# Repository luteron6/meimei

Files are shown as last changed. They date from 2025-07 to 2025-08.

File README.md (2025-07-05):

# meimei
A simple, wireless, 75% keyboard! Not too big or small. It runs ZMK.



# Why?
My first exposure to keyboards was through Hack Club's #hackpad, in which I made a 5-key macropad with an encoder and screen. I've never had a regular mechanical keyboard, and this is my attempt at making one. It has a function row, all the necessary keys for typing, and a rotary encoder. Since I mainly use a laptop, I wanted this keyboard to be fully wireless.

## Code - ZMK
After watching many [Joe Scotto](https://www.youtube.com/@joe_scotto) videos, I came to the conclusion that the only reasonable microcontroller to use was the [nice!nano v2](https://nicekeyboards.com/docs/nice-nano/pinout-schematic).

It's suggested to run ZMK as the firmware for bluetooth, so I learned ZMK for this keyboard. Previously I've used QMK, but ZMK is quite different as it uses a Github Actions workflow to compile the firmware file. The firmware for this keyboard lives in [this](https://github.com/luteron6/zmk-config-meimei) repository. Simply go to the [Actions](https://github.com/luteron6/zmk-config-meimei/actions) tab, open the most recent workflow, download the firmware Artifact, unzip the firmware, and flash it to the nice!nano. 

All the source files for ZMK are in the /Code folder in this repository.

## PCB
I made the PCB in KiCad, using [Joe Scotto's symbol/footprint/3D model library](https://github.com/joe-scotto/scottokeebs/tree/main/Extras/ScottoKicad).

It was really helpful as his footprints had 3D models linked to them, because it transferred into Onshape when I worked on my CAD. I included a power button to turn off the keyboard when I travel with it, and an encoder for good measure.

I chose to go with the biggest reasonable battery for this project, so I chose a 3048128 3400mAh battery. According to the [ZMK Power Profiler](https://zmk.dev/power-profiler), this keyboard will last 1 year and 1 month. So basically forever. And ZMK can report battery usage over bluetooth, so this keyboard will literally never die.

The PCB files are in the /PCB folder, including the KiCad source files and the Gerbers for production.



## CAD
As mentioned above, the CAD was made in Onshape. The case has two parts, both of which are in the /CAD folder along with the STEP file of everything. It's meant to be 3D printed and screwed together using threaded inserts and M2 screws.

## BOM
| Item | QTY Needed | QTY Purchased | Price | Description | Link |
|---|---|----|---|---|---|
| Keyswitches | 74 | 90 | $27.98  | Clicky switches | [Link](https://www.amazon.com/Akko-Keyboard-Diffuser-Mechanical-Structure/dp/B0DJNSK6TD/) |
| Keycaps (Japanese Maple) | | | $25.99  | | [Link](https://www.amazon.com/Japanese-Keycaps-Sublimation-Mechanical-Keyboard/dp/B08Y6S1N3X/) |
| nice!nano | 1 | 1  | $24.99  | microcontroller | [Link](https://www.littlekeyboards.com/products/nice-nano) |
| PCB | 1 | 5  | $30.00  | JLCPCB (also includes shipping) | |
| diodes | 70 | 125 | $5.99  | SOD-123 package diodes | [Link](https://www.amazon.com/100-Pieces-1N4148W-Switching-High-Speed/dp/B079KJX5J9/) |
| Stabilizers | | | $18.99  | Spacebar/2u stabilizers | [Link](https://www.amazon.com/DUROCK-Stabilizers-Translucent-Keyboard-Mechanical/dp/B0B2RVN19F/) |
| peel-away sockets | 2 | 2  | $6.00 | socketing the microcontroller | [Link](https://ringerkeys.com/products/peel-a-way-sockets?variant=40212560576594) |
| peel-away pins | 2 | 2  | $6.00 | socketing the microcontroller | [Link](https://ringerkeys.com/products/peel-a-way-sockets?variant=40212560609362) |
| Battery | 1 | 1  | $8.99 | A 3048128 3400mAh battery | [Link](https://www.amazon.com/YTKavq-3400mAh-Battery-Rechargeable-Connector/dp/B08TTJ79JV/) |
| Latching Switches | 1 | 3  | $7.99 | Power on/off switch | [Link](https://www.amazon.com/Gebildet-Prewired-Waterproof-Self-Locking-Stainless/dp/B0BXPFW69R/) |
| littlekeyboards shipping | | | $6.00 | | |
| ringerkeys shipping | | | $6.00 | | |
| Total | | | $174.92 | | |

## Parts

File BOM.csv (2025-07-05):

Item | QTY Needed | QTY Purchased | Price | Description | Link
Keyswitches | 74 | 90 | $27.98 | Clicky switches | https://www.amazon.com/Akko-Keyboard-Diffuser-Mechanical-Structure/dp/B0DJNSK6TD/
Keycaps (Japanese Maple) |  |  | $25.99 |  | https://www.amazon.com/Japanese-Keycaps-Sublimation-Mechanical-Keyboard/dp/B08Y6S1N3X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
nice!nano | 1 | 1 | $24.99 | microcontroller | https://www.littlekeyboards.com/products/nice-nano
PCB | 1 | 5 | $30.00 | JLCPCB (also includes shipping)
diodes | 70 | 125 | $5.99 | SOD-123 package diodes | https://www.amazon.com/100-Pieces-1N4148W-Switching-High-Speed/dp/B079KJX5J9/
Stabilizers |  |  | $18.99 | Spacebar/2u stabilizers | https://www.amazon.com/DUROCK-Stabilizers-Translucent-Keyboard-Mechanical/dp/B0B2RVN19F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
peel-away sockets | 2 | 2 | $6.00 | socketing the microcontroller | https://ringerkeys.com/products/peel-a-way-sockets?variant=40212560576594
peel-away pins | 2 | 2 | $6.00 | socketing the microcontroller | https://ringerkeys.com/products/peel-a-way-sockets?variant=40212560609362
Battery | 1 | 1 | $8.99 | A 3048128 3400mAh battery | https://www.amazon.com/YTKavq-3400mAh-Battery-Rechargeable-Connector/dp/B08TTJ79JV/
Latching Switches | 1 | 3 | $7.99 | Power on/off switch | https://www.amazon.com/Gebildet-Prewired-Waterproof-Self-Locking-Stainless/dp/B0BXPFW69R/
littlekeyboards shipping |  |  | $6.00
ringerkeys shipping |  |  | $6.00
Total |  |  | $174.92

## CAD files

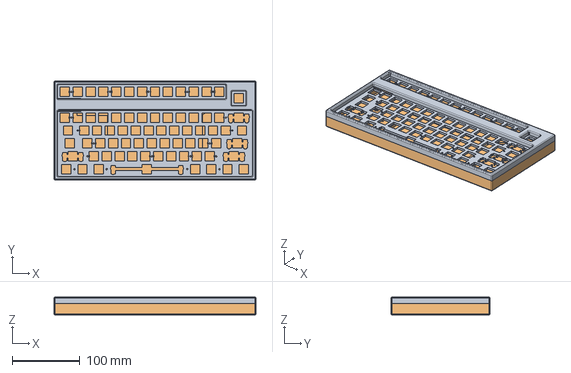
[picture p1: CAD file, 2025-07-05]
CAD/Assembly.step
298.5 x 146.1 x 26.6 mm

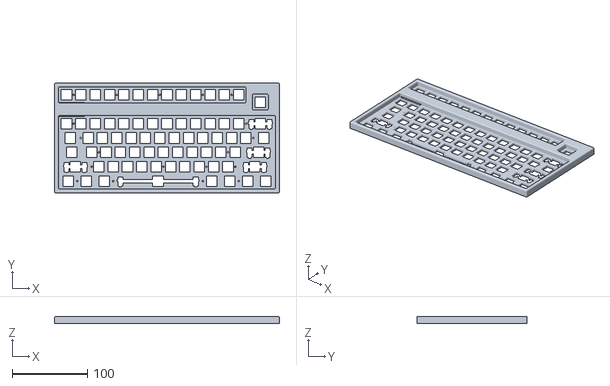
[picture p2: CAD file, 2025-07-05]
CAD/top.stl
298.5 x 146.1 x 9.60

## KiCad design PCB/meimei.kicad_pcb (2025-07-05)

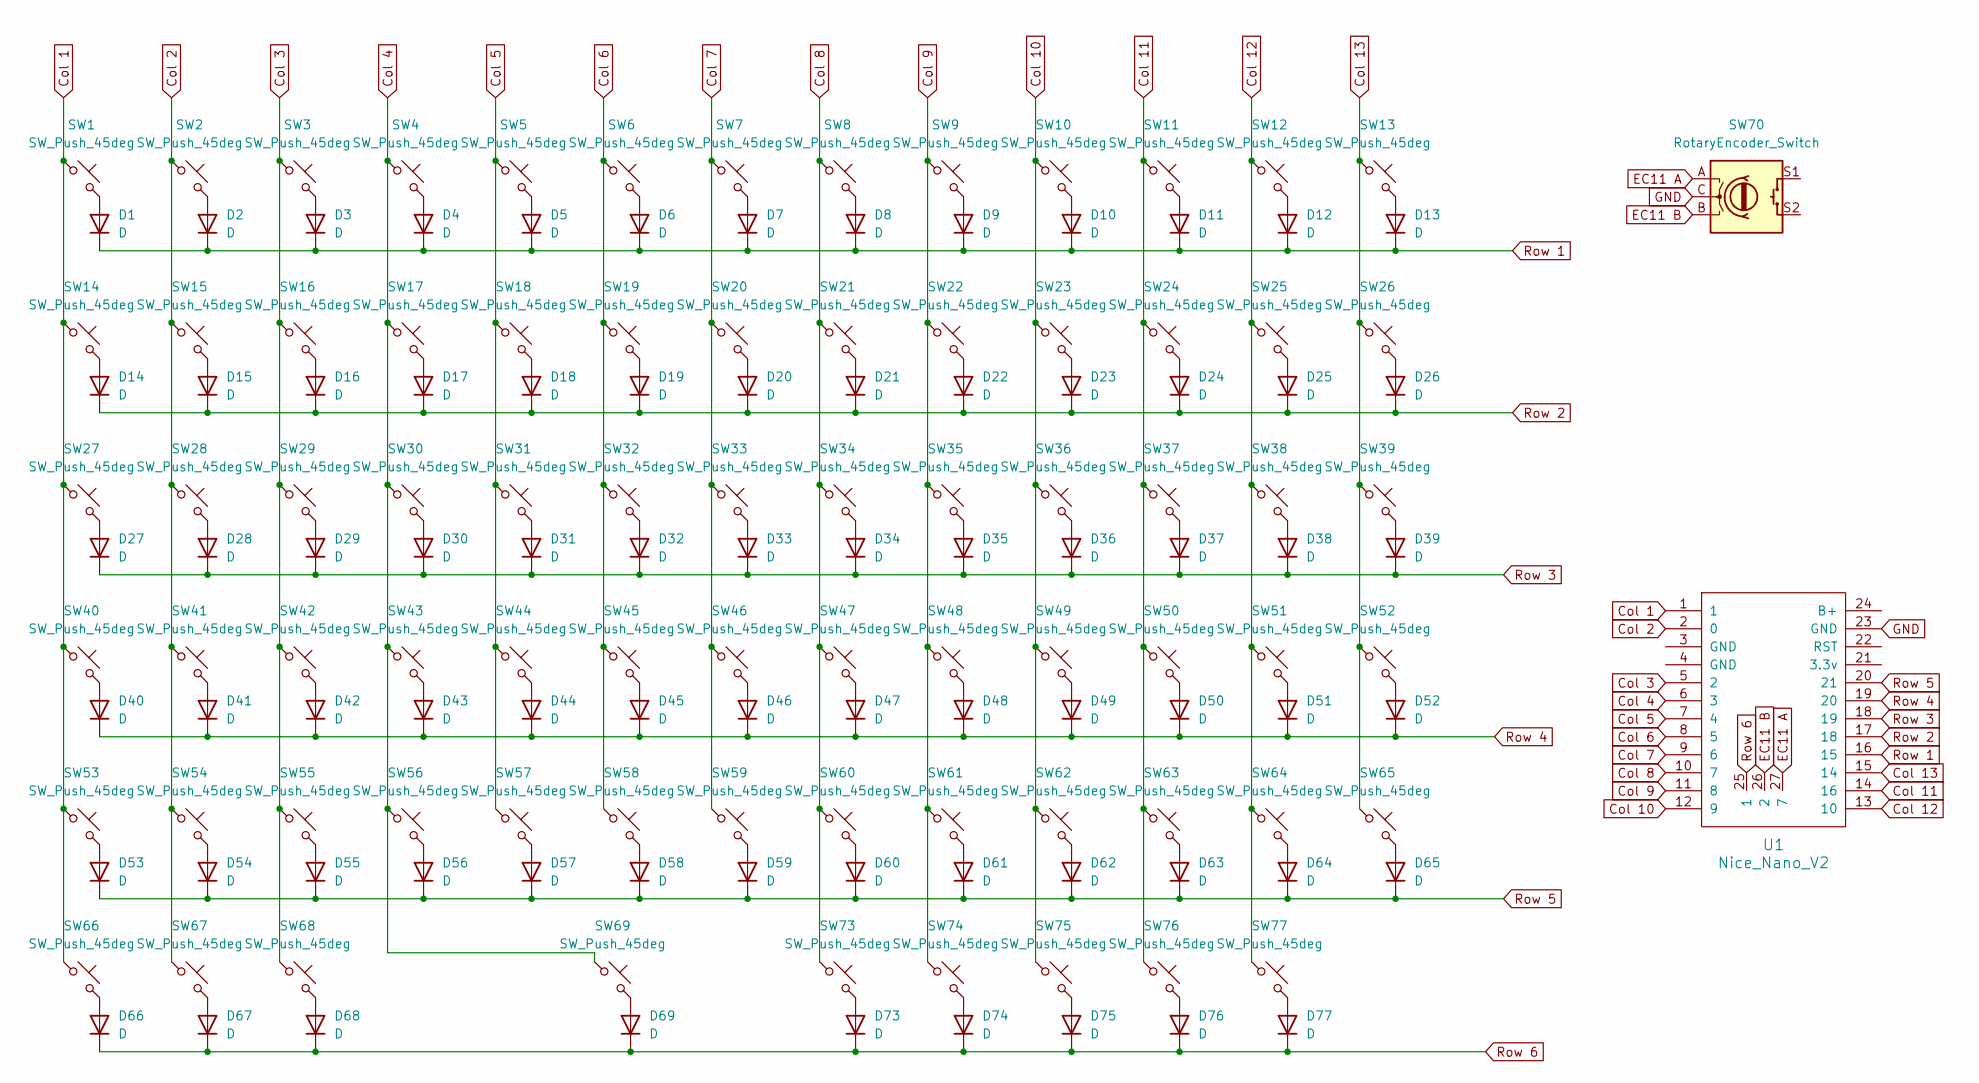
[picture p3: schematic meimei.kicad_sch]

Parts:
D1, D2, D3, D4, D5, D6, D7, D8, D9, D10, D11, D12, D13, D14, D15, D16, D17, D18, D19, D20, D21, D22, D23, D24, D25, D26, D27, D28, D29, D30, D31, D32, D33, D34, D35, D36, D37, D38, D39, D40, D41, D42, D43, D44, D45, D46, D47, D48, D49, D50, D51, D52, D53, D54, D55, D56, D57, D58, D59, D60, D61, D62, D63, D64, D65, D66, D67, D68, D69, D73, D74, D75, D76, D77: D; D_SOD-123
SW1, SW2, SW3, SW4, SW5, SW6, SW7, SW8, SW9, SW10, SW11, SW12, SW13, SW14, SW15, SW16, SW17, SW18, SW19, SW20, SW21, SW22, SW23, SW24, SW25, SW26, SW28, SW29, SW30, SW31, SW32, SW33, SW34, SW35, SW36, SW37, SW38, SW39, SW41, SW42, SW43, SW44, SW45, SW46, SW47, SW48, SW49, SW50, SW51, SW54, SW55, SW56, SW57, SW58, SW59, SW60, SW61, SW62, SW63: SW_Push_45deg; MX_PCB_1.00u
SW27, SW52: SW_Push_45deg; MX_PCB_1.50u
SW40: SW_Push_45deg; MX_PCB_1.75u
SW53, SW64: SW_Push_45deg; MX_PCB_2.25u
SW65: SW_Push_45deg; MX_PCB_2.00u
SW66, SW67, SW68, SW73, SW74, SW75, SW76: SW_Push_45deg; MX_PCB_1.25u
SW69: SW_Push_45deg; MX_PCB_6.25u
SW70: RotaryEncoder_Switch; Encoder_EC11_MX
SW77: SW_Push_45deg; MX_PCB_2.75u
U1: Nice_Nano_V2

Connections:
Col 1: SW1.1, SW14.1, SW27.1, SW40.1, SW53.1, SW66.1, U1.1
Col 2: SW2.1, SW15.1, SW28.1, SW41.1, SW54.1, SW67.1, U1.2 (0)
Col 3: SW3.1, SW16.1, SW29.1, SW42.1, SW55.1, SW68.1, U1.5 (2)
Col 4: SW4.1, SW17.1, SW30.1, SW43.1, SW56.1, SW69.1, U1.6 (3)
Col 5: SW5.1, SW18.1, SW31.1, SW44.1, SW57.1, U1.7 (4)
Col 6: SW6.1, SW19.1, SW32.1, SW45.1, SW58.1, U1.8 (5)
Col 7: SW7.1, SW20.1, SW33.1, SW46.1, SW59.1, U1.9 (6)
Col 8: SW8.1, SW21.1, SW34.1, SW47.1, SW60.1, SW73.1, U1.10 (7)
Col 9: SW9.1, SW22.1, SW35.1, SW48.1, SW61.1, SW74.1, U1.11 (8)
Col 10: SW10.1, SW23.1, SW36.1, SW49.1, SW62.1, SW75.1, U1.12 (9)
Col 11: SW11.1, SW24.1, SW37.1, SW50.1, SW63.1, SW76.1, U1.14 (16)
Col 12: SW12.1, SW25.1, SW38.1, SW51.1, SW64.1, SW77.1, U1.13 (10)
Col 13: SW13.1, SW26.1, SW39.1, SW52.1, SW65.1, U1.15 (14)
EC11 A: SW70.A, U1.27 (7)
EC11 B: SW70.B, U1.26 (2)
GND: SW70.C, U1.23 (GND)
unnamed: D1.2 (A), SW1.2
unnamed: D2.2 (A), SW2.2
unnamed: D3.2 (A), SW3.2
unnamed: D4.2 (A), SW4.2
unnamed: D5.2 (A), SW5.2
unnamed: D6.2 (A), SW6.2
unnamed: D7.2 (A), SW7.2
unnamed: D8.2 (A), SW8.2
unnamed: D9.2 (A), SW9.2
unnamed: D10.2 (A), SW10.2
unnamed: D11.2 (A), SW11.2
unnamed: D12.2 (A), SW12.2
unnamed: D13.2 (A), SW13.2
unnamed: D14.2 (A), SW14.2
unnamed: D15.2 (A), SW15.2
unnamed: D16.2 (A), SW16.2
unnamed: D17.2 (A), SW17.2
unnamed: D18.2 (A), SW18.2
unnamed: D19.2 (A), SW19.2
unnamed: D20.2 (A), SW20.2
unnamed: D21.2 (A), SW21.2
unnamed: D22.2 (A), SW22.2
unnamed: D23.2 (A), SW23.2
unnamed: D24.2 (A), SW24.2
unnamed: D25.2 (A), SW25.2
unnamed: D26.2 (A), SW26.2
unnamed: D27.2 (A), SW27.2
unnamed: D28.2 (A), SW28.2
unnamed: D29.2 (A), SW29.2
unnamed: D30.2 (A), SW30.2
unnamed: D31.2 (A), SW31.2
unnamed: D32.2 (A), SW32.2
unnamed: D33.2 (A), SW33.2
unnamed: D34.2 (A), SW34.2
unnamed: D35.2 (A), SW35.2
unnamed: D36.2 (A), SW36.2
unnamed: D37.2 (A), SW37.2
unnamed: D38.2 (A), SW38.2
unnamed: D39.2 (A), SW39.2
unnamed: D40.2 (A), SW40.2
unnamed: D41.2 (A), SW41.2
unnamed: D42.2 (A), SW42.2
unnamed: D43.2 (A), SW43.2
unnamed: D44.2 (A), SW44.2
unnamed: D45.2 (A), SW45.2
unnamed: D46.2 (A), SW46.2
unnamed: D47.2 (A), SW47.2
unnamed: D48.2 (A), SW48.2
unnamed: D49.2 (A), SW49.2
unnamed: D50.2 (A), SW50.2
unnamed: D51.2 (A), SW51.2
unnamed: D52.2 (A), SW52.2
unnamed: D53.2 (A), SW53.2
unnamed: D54.2 (A), SW54.2
unnamed: D55.2 (A), SW55.2
unnamed: D56.2 (A), SW56.2
unnamed: D57.2 (A), SW57.2
unnamed: D58.2 (A), SW58.2
unnamed: D59.2 (A), SW59.2
unnamed: D60.2 (A), SW60.2
unnamed: D61.2 (A), SW61.2
unnamed: D62.2 (A), SW62.2
unnamed: D63.2 (A), SW63.2
unnamed: D64.2 (A), SW64.2
unnamed: D65.2 (A), SW65.2
unnamed: D66.2 (A), SW66.2
unnamed: D67.2 (A), SW67.2
unnamed: D68.2 (A), SW68.2
unnamed: D69.2 (A), SW69.2
unnamed: D73.2 (A), SW73.2
unnamed: D74.2 (A), SW74.2
unnamed: D75.2 (A), SW75.2
unnamed: D76.2 (A), SW76.2
unnamed: D77.2 (A), SW77.2
Row 1: D1.1 (K), D2.1 (K), D3.1 (K), D4.1 (K), D5.1 (K), D6.1 (K), D7.1 (K), D8.1 (K), D9.1 (K), D10.1 (K), D11.1 (K), D12.1 (K), D13.1 (K), U1.16 (15)
Row 2: D14.1 (K), D15.1 (K), D16.1 (K), D17.1 (K), D18.1 (K), D19.1 (K), D20.1 (K), D21.1 (K), D22.1 (K), D23.1 (K), D24.1 (K), D25.1 (K), D26.1 (K), U1.17 (18)
Row 3: D27.1 (K), D28.1 (K), D29.1 (K), D30.1 (K), D31.1 (K), D32.1 (K), D33.1 (K), D34.1 (K), D35.1 (K), D36.1 (K), D37.1 (K), D38.1 (K), D39.1 (K), U1.18 (19)
Row 4: D40.1 (K), D41.1 (K), D42.1 (K), D43.1 (K), D44.1 (K), D45.1 (K), D46.1 (K), D47.1 (K), D48.1 (K), D49.1 (K), D50.1 (K), D51.1 (K), D52.1 (K), U1.19 (20)
Row 5: D53.1 (K), D54.1 (K), D55.1 (K), D56.1 (K), D57.1 (K), D58.1 (K), D59.1 (K), D60.1 (K), D61.1 (K), D62.1 (K), D63.1 (K), D64.1 (K), D65.1 (K), U1.20 (21)
Row 6: D66.1 (K), D67.1 (K), D68.1 (K), D69.1 (K), D73.1 (K), D74.1 (K), D75.1 (K), D76.1 (K), D77.1 (K), U1.25 (1)

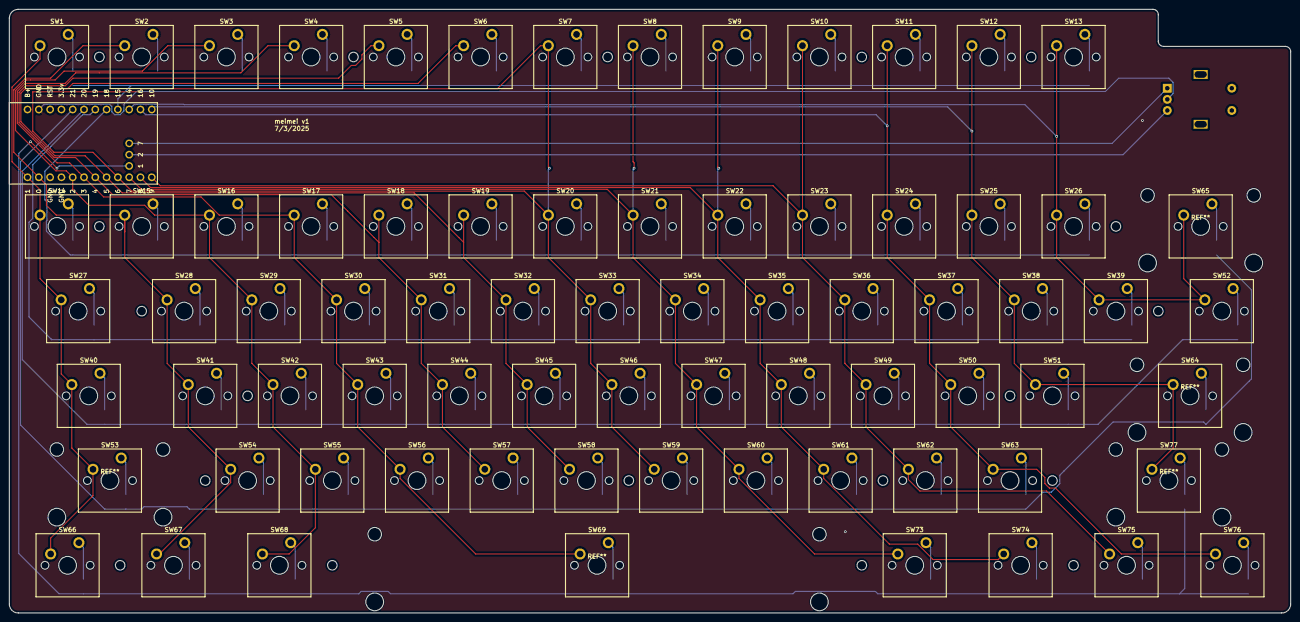
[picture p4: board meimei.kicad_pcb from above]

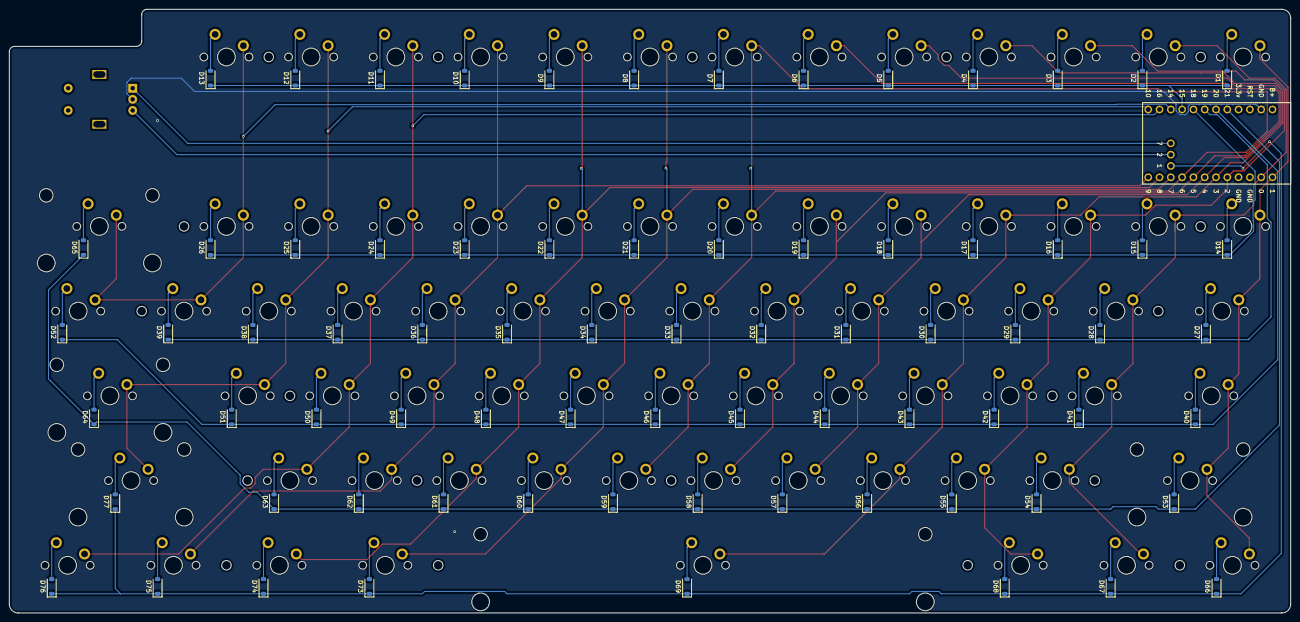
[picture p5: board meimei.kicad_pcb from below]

Board: 2 copper layers, 288.1 x 135.7 mm, 150 parts (74 on the bottom side), 96 nets.

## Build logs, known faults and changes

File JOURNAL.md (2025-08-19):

---
title: "meimei"
author: "@luteron6"
description: "A keyboard that's not too big and not too small"
created_at: "2025-06-20"
---
# meimei
Made by @luteron6

Total hours so far: 19

Cost: $179.96 (after shipping)

I don't have a (regular) mechanical keyboard, and so I thought I'd build one for Hack Club's #highway YSWS.

I've been thinking about this for a while, and here's what I want (some goals):
* 80%. I don't use all those extra keys, so 80% is great. I'm going to copy my existing laptop layout (kind of).
* A rotary encoder for volume control.
* Bluetooth with a battery
* USB-C
* Clicky keys :)

## Day 1 - 6/20/2025 - 7:55 AM (5 hours)
From my research, I've found that Cherry Blues are the typical 'clicky' switches. So I'll go with those. For the keycaps, I found [these](https://www.amazon.com/Japanese-Keycaps-Sublimation-Mechanical-Keyboard/dp/B08Y6S1N3X/).

I also found that the [nice!nano](https://nicekeyboards.com/nice-nano/) microcontroller is the typical bluetooth microcontroller used on keyboards. Apparently it's best with ZMK firmware, so I'll have to learn that keyboard firmware to make the .uf2 (I only know QMK). The docs also suggest socketing the nice!nano, so I'll try that. I found these sockets and pins: [here](https://ringerkeys.com/products/peel-a-way-sockets?variant=40212560576594).

Here's the start of my BOM:
* [Cherry Blue MX Keyswitches](https://www.amazon.com/Switches-Mechanical-Keyboard-Pre-Lubed-Pin-Enhanced/dp/B0CJ8SGL6B/): $32.99
* [Keycaps](https://www.amazon.com/Japanese-Keycaps-Sublimation-Mechanical-Keyboard/dp/B08Y6S1N3X/): $25.99
* [nice!nano](24.99) WOW! That's *expensive*: $24.99
* [Sockets/Pins](https://ringerkeys.com/products/peel-a-way-sockets?variant=40212560609362): $8.00
* [1N4148 Diodes](https://www.amazon.com/BOJACK-Switching-IN4148-Electronic-Silicon/dp/B07Q4F3Y5W/): $5.99

Here's the layout I want to go with:


I drew out my electrical matrix:<br>

Then I created my schematic:<br> 

Phew! It's done. My PCB, that is: <br> 

I'm going to start on my case after I add this repo to the submissions.yml file. But I'm going to close this journal log now, it's been a while.

## Day 2 - 7/2/2025 last night (4 hours)
OK last night I stayed up way too late making my case. It was like past 11, so I just went to sleep without journaling. Anyway, I started and almost finished my case. Here's my PCB:



I also decided to add a metal latching switch for turning the keyboard on and off, but the only downside is that it must be 'on' to charge. I also put a spot for the battery in there. I also added holes in the PCB so I can screw the plate into the bottom:



The whole case looks like this:

I think that's it for the case. Today (7/3) I'll try to work on the ZMK firmware.

## Day 3 - 7/3/2025 - 12:22 PM (3 hours)
I just spent waaaayyyyyyy too long trying to figure that out. Hackatime says I spent around 2 hours trying to configure ZMK, then I probably spent another hour waiting for the workflow (collectively) to run and troubleshooting the errors. But it did end up running, and [here](https://github.com/luteron6/zmk-config-meimei/actions/runs/16058502554e) are the results.

I think it's almost ready to submit!

## Day 4 - 7/27/2025 - 7:58 AM (1 hour)
It got approved, I got the grant, and yesterday I purchased all the parts for the keyboard. I could only find some parts on certain sites, so I got those first. The rest was from Amazon. I was looking to source from Aliexpress, but stuff wasn't looking much cheaper there. So most of it's coming from Amazon.

## Day 5-8 - ~8/18/2025 - 8:29 PM (6 hours)
The stuff started trickling in a couple weeks ago, but I was waiting forever for those diodes. They came today, so I was able to spend ~2 hours today to finish it. (I've been working on it for the past couple days). When the first parts got here, I realized I had miscalculated the length of the latching switch. I had to reprint the right side of the case, both the top half and the bottom half.

<p align="center">
  
  <br>
  The old design
</p>

<p align="center">
  
  <br>
  The new design
</p>

That fit fine. If I had the opportunity to redo my PCB too, I would probably make the cutout bigger:
<p align="center">
  <br>
  The optimal switch placement
</p>

I also had to recompile my firmware ~10 times to get the encoder working. The [current firmware](https://github.com/luteron6/zmk-config-meimei/actions/runs/17058386749) works as expected. The knob controls the volume in 2% incremements. Then I realized the keyboard had the tilde keypress instead of the grave accent, so I had to change that. So the firmware above has all the issues fixed.

And here are some build photos:

<p align="center">
    
    <br>
    
    <br>
    
    
</p>

I had an awesome time making this keyboard, and I'm satisfied with how it came out! Thanks Hack Club!

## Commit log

2025-07-05 All source and production files and README
    missing the CAD STEP file
    [BOM.csv, meimei.kicad_pcb, meimei.kicad_sch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]
2025-07-05 Added STEP file
    GH says STEP file with PCB is too big to upload
    [Assembly.step]
